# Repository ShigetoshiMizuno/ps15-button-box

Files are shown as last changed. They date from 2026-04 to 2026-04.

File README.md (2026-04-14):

# PS-15 Button Box

A 3D-printable single-button enclosure for the Seimitsu PS-15 arcade button.

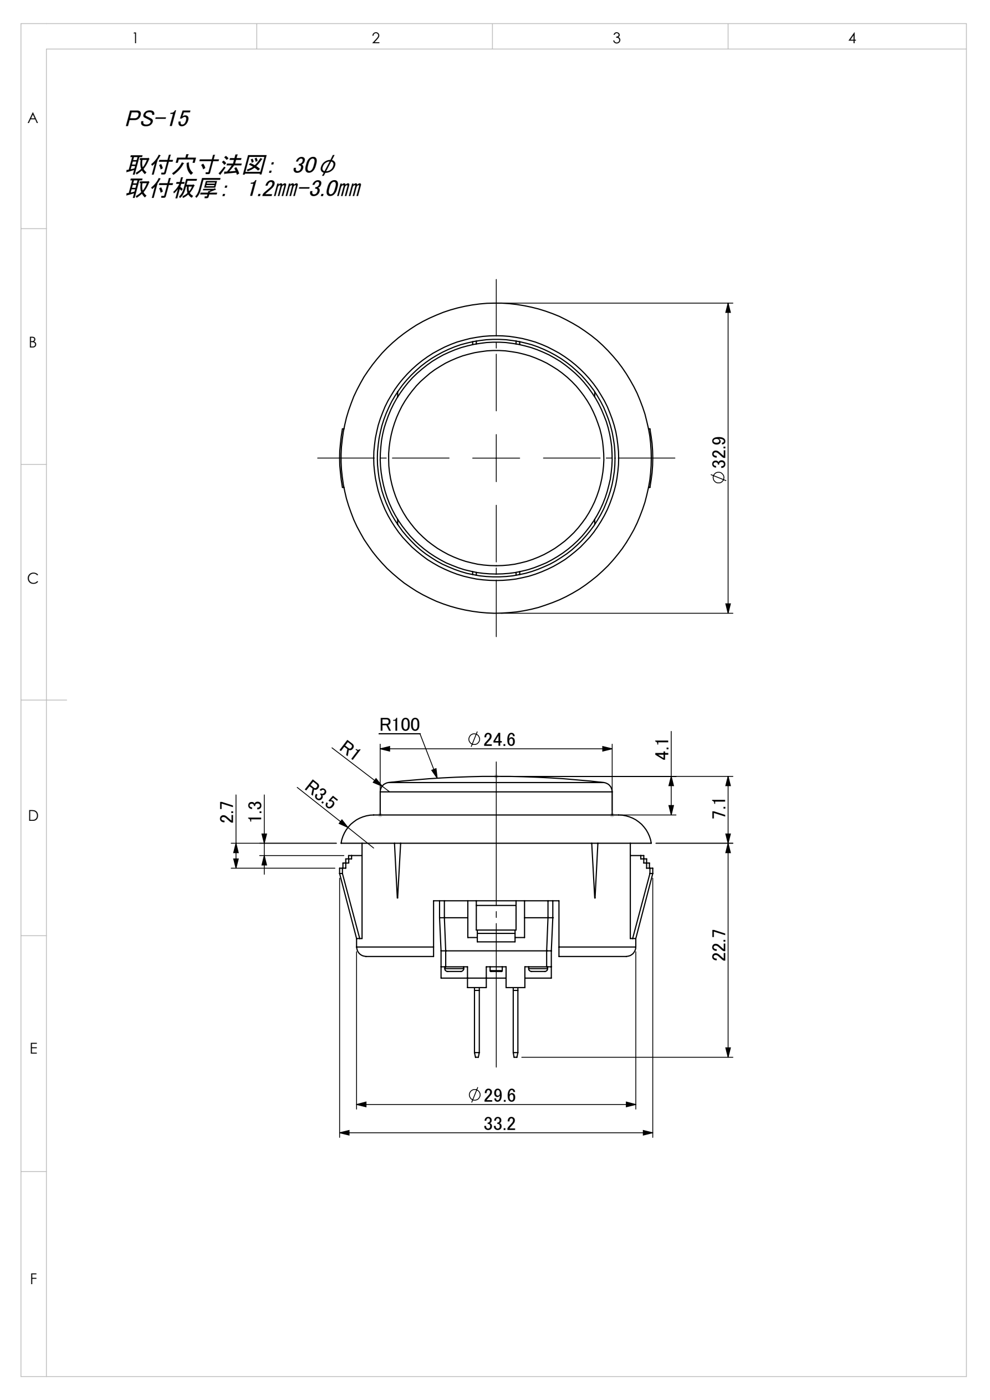
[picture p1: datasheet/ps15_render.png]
PS-15 Box Render


## Features

- Designed for **Seimitsu PS-15** (φ30mm mount hole, 1.2–3.0mm panel thickness)
- **Perfect cube**: 47 × 47 × 47mm assembled (body 44mm + lid 3mm)
- **FDM-optimized**: +0.2mm hole compensation, no supports required for either part
- **Two-point diagonal fastening**: M3×50 button-head bolt + M3 heat-press insert nut (8mm)
- **Dual mounting**: screw to wooden panel (φ4 wood screw) or use standalone
- **Wire slot**: U-slot 12mm × 10mm on right side wall
- **Engravings**: "NongSoft LLC / 2026" inside box bottom + lid back

## Files

| File | Description |
|---|---|
| `ps15_box.scad` | OpenSCAD source (all parameters adjustable) |
| `ps15_box_body.stl` | Body STL for 3D printing |
| `ps15_lid.stl` | Lid STL for 3D printing |
| `ps15_box_body.step` | Body STEP (for CAD import) |
| `ps15_lid.step` | Lid STEP (for CAD import) |
| `ps15_box_spec.md` | Full specification sheet |
| `stl_to_step.py` | FreeCAD 1.1 STL→STEP conversion script |

## Print Settings

| Parameter | Value |
|---|---|
| Material | **PETG** (PLA not recommended — low heat deflection for heat inserts) |
| Layer height | 0.2mm |
| Walls | 6 perimeters |
| Infill | 30–40% Gyroid |
| Body orientation | Open side up, no supports |
| Lid orientation | Flat side (inner face) down, no supports |

## Hardware

| Item | Spec | Qty |
|---|---|-----|
| M3 button-head bolt | M3 × 50mm | 2 |
| Heat-press insert nut | M3, OD φ4.6mm, L 8mm, brass | 2 |
| Button | Seimitsu PS-15 | 1 |

**Insert nut sources:**
- MISUMI: `BNTS3-8` (M3, brass, L=8mm)
- Amazon.co.jp: uxcell / SUNGQ 50-pack

## OpenSCAD Usage

### Customizer

- **断面表示 (Section view)**: toggle `show_section`, choose axis and position
- **出力 (Export)**: set `render_part` — 0=view, 1=body, 2=lid

### Re-export STL

```bat
set SCAD="C:\Program Files\OpenSCAD\openscad.exe"
%SCAD% -D "render_part=1" -o ps15_box_body.stl ps15_box.scad
%SCAD% -D "render_part=2" -o ps15_lid.stl      ps15_box.scad
```

### Re-export STEP (requires FreeCAD 1.1)

```bat
freecadcmd.exe stl_to_step.py
```

## License

[MIT License](LICENSE)

---

*Designed by NongSoft LLC — 2026*

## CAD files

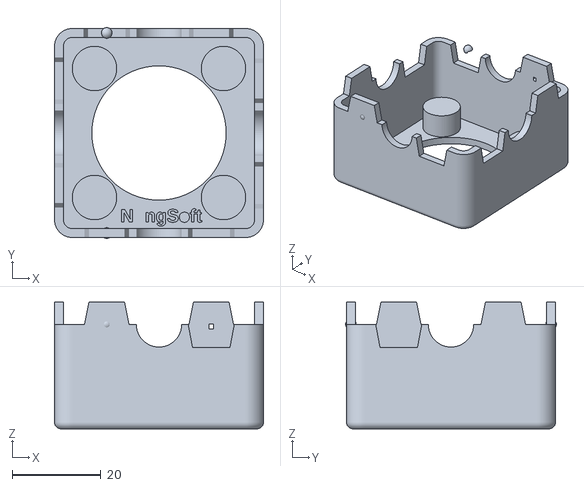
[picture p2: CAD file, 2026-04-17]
ps15_box_half.stl
47.0 x 47.4 x 28.5

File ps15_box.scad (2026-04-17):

// ============================================================
//  PS-15 スイッチボックス（1ボタン）v14 — 上下同一ハーフ設計
//  対象: Seimitsu PS-15
//  単位: mm
// ============================================================
//
//  【設計方針】
//    同一形状のハーフを2個印刷し、組み合わせてボックスを構成。
//    同じ印刷設定・同じ寸法誤差 → サイズ合わせ問題を根本解消。
//
//  【組立方法】
//    下ハーフ: 天面を上（正立）に置く
//    上ハーフ: ひっくり返して（天面を下向き）下ハーフに重ねる
//              → ボタン穴が最上面に来る
//    固定   : 4コーナー M3ボルト（長さは echo 参照）
//
//  【固定方式（4コーナー）】
//    インサートナット（M3）を下ハーフ底面外側から熱圧入
//    上ハーフ（反転）天面のカウンターボアからボルトを通す
//
//  【底面フィレット】接地面（Z=0側）の水平エッジ4本を R1.5mm でフィレット。
//                    反転した上ハーフの天面（組立時の上面）も同時に丸まる。
//                    合わせ面は直角を維持（ハーフ同士がぴったり接する）。
//
//  【配線】全4壁（前後左右）合わせ面に半円切り欠き（2ハーフ合体で円φ10mm）
//          連接時（daisy-chain）に各方向へケーブルが通せる
//
//  【位置合わせ（ラップジョイント・段継ぎ方式）】
//    E/W（東西）壁の合わせ面（Z=HALF_H）に段差δ=1.5mm の舌（凸）と溝（凹）を設ける。
//    下ハーフ E 壁に舌、W 壁に溝。反転した上ハーフは E/W が入れ替わり凸↔凹が噛み合う。
//    南(+Y) → 北(-Y) スライドで嵌合・自己ストップ。
//    変換: (x,y,z) → (OUTER_W-x, y, 2*HALF_H-z)
//
// ============================================================

/* ─── PS-15 仕様 ─── */
BTN_HOLE_D  = 30;    // 取付穴径 φ30mm
BTN_DEPTH   = 22.7;  // パネル下本体深さ（端子含む）

/* ─── ボックス基本寸法 ─── */
WALL        = 2.0;   // 側壁厚
BOT_T       = 2.0;   // 底面板厚（ボタン穴・cbore・インサート穴が集中する面）
HALF_H      = 23.5;  // 各ハーフ高さ
// 各ハーフはオープンカップ設計: Z=0〜BOT_T が底板、Z=BOT_T〜HALF_H が開口内部
INNER_H_HALF = HALF_H - BOT_T;           // 各ハーフ内高 = 21.5mm（開口カップ）
INNER_W     = 43;    // 内寸 X
INNER_D     = 43;    // 内寸 Y
CORNER_R      = 4.0;   // 外形コーナー半径
BOTTOM_FILLET = 1.5;   // 底面4辺のフィレット半径（合わせ面はシャープ保持）
INNER_CORNER_R = CORNER_R - WALL;        // 内壁コーナー半径 = 2mm

/* ─── 固定穴（4コーナー）─── */
MOUNT_INSET  = 9.0;  // コーナーからの内側オフセット（最小 9mm）
MOUNT_HOLE_D = 4.5;  // クリアランス穴径（M3 ボルト用）
MOUNT_CBORE_D= 9.0;  // カウンターボア径（M3 ボタンヘッドボルト頭）
CBORE_H      = 1.0;  // カウンターボア深さ（残し厚 = BOT_T - CBORE_H = 1.0mm）

/* ─── M3 インサートナット（熱圧入・底面外側から挿入）─── */
INSERT_OD   = 4.6;   // インサートナット外径
INSERT_L    = 8.0;   // インサートナット長さ
PILOT_D     = INSERT_OD + 0.1;           // 下穴径 = 4.7mm
PILOT_DEPTH = INSERT_L + 0.5;            // 下穴深さ = 8.5mm

/* ─── 内側ボス（底面板内側に突出）─── */
// ボス高さ = 下穴深さ - 底板厚 → ボス上面が下穴の上端に一致
BOSS_H      = PILOT_DEPTH - BOT_T;       // 6.5mm
BOSS_OD     = 10.0;  // ボス外径（≥ 2×INSERT_OD = 9.2mm）

/* ─── 位置合わせ凸凹（E/W壁・合わせ面 ラップジョイント方式）─── */
// 段継ぎ: E壁内側 1mm に舌（凸）、W壁内側 1mm に溝（凹）を配置。
// 下ハーフ反転で凸↔凹が入れ替わり噛み合う（同一ハーフ設計）。
STEP_DELTA   = 1.5;    // 段差高さ（mm）
STEP_Y_START = 29;     // 舌/溝 Y 開始位置（mm）
STEP_Y_END   = 43;     // 舌/溝 Y 終了位置（mm）
STEP_CLEAR   = 0.35;   // FDM 片側クリア（バンプ頂点+0.3mm分+余裕0.05mm確保）

// ---- ディテント (E1: 球バンプ) ----
DETENT_BUMP_R  = 0.30;   // バンプ半径（舌上面に凸）
DETENT_DIVOT_R = 0.45;   // ディンプル半径（溝天井に凹、CLEAR込み）
DETENT_Y       = (STEP_Y_START + STEP_Y_END) / 2;  // = 36（ストローク中央）

/* ─── 配線穴（合わせ面・半円切り欠き／合体で円形）─── */
// 全4壁に配置（連接時 daisy-chain 対応）
WIRE_D = 10.0;   // 合体時の円径（各ハーフは半円切り欠き）

/* ─── 算出値 ─── */
OUTER_W = INNER_W + 2 * WALL;   // 47.0mm
OUTER_D = INNER_D + 2 * WALL;   // 47.0mm

$fn = 64;

/* [断面表示] */
show_section = true;   // 断面表示を有効にする
cut_axis = 2;          // [0:X軸, 1:Y軸, 2:Z軸]
// デフォルト = MAX → スライダー最大位置でモデル全体が表示される
// X: ハーフ1(0-47) + gap(15) + ハーフ2(62-109) → MAX=110 で全表示
cut_x = 110;           // [0:1:110]
// Y: 外寸 47mm → MAX=50 で全表示
cut_y = 50;            // [0:1:50]
// Z: 0〜HALF_H=23.5mm → MAX=25 で全表示
cut_z = 25;            // [0:1:25]

/* [出力] */
// 0: ビュー  1: ハーフ単体（STL出力用）
render_part = 0;       // [0:ビュー, 1:ハーフ単体]
// FDM 収縮補正: 穴径を指定値だけ拡大（ボス等の外形には不適用）
hole_comp = 0.2;       // [0:0.05:0.5]

// 4コーナー: 前左・前右・後左・後右
mount_pts = [
    [MOUNT_INSET,             MOUNT_INSET            ],  // 前左
    [OUTER_W - MOUNT_INSET,   MOUNT_INSET            ],  // 前右
    [MOUNT_INSET,             OUTER_D - MOUNT_INSET  ],  // 後左
    [OUTER_W - MOUNT_INSET,   OUTER_D - MOUNT_INSET  ]   // 後右
];

// ============================================================
//  モジュール: 角Rつき矩形柱
// ============================================================
module rounded_box(w, d, h, r) {
    hull() {
        translate([    r,     r, 0]) cylinder(r = r, h = h);
        translate([w - r,     r, 0]) cylinder(r = r, h = h);
        translate([    r, d - r, 0]) cylinder(r = r, h = h);
        translate([w - r, d - r, 0]) cylinder(r = r, h = h);
    }
}

// ============================================================
//  モジュール: 外殻（底面4辺フィレット・合わせ面はシャープ）
//    minkowski で球をスイープしてフィレット生成、上端は cube でクリップ
// ============================================================
module outer_shell() {
    r = BOTTOM_FILLET;
    intersection() {
        minkowski() {
            translate([r, r, r])
                rounded_box(OUTER_W - 2*r, OUTER_D - 2*r, HALF_H - r, CORNER_R - r);
            sphere(r = r);
        }
        // 上端クリップ（合わせ面 Z=HALF_H 以上を落として直角に保つ）
        cube([OUTER_W, OUTER_D, HALF_H]);
    }
}

// ============================================================
//  モジュール: 配線穴（4壁・合わせ面半円切り欠き）
//    合わせ面 Z=HALF_H に中心を持つ円柱を各壁中央に配置 → 壁の上端を半円に切り欠く
//    2ハーフ合体で円φWIRE_D になる（daisy-chain 連接時は各方向にケーブル通し可）
// ============================================================
module wire_half_hole() {
    hole_d = WIRE_D + hole_comp;
    // 前壁（Y=0）: 軸Y方向
    translate([OUTER_W / 2, -0.1, HALF_H])
        rotate([-90, 0, 0])
            cylinder(d = hole_d, h = WALL + 0.2);
    // 後壁（Y=OUTER_D）: 軸Y方向
    translate([OUTER_W / 2, OUTER_D - WALL - 0.1, HALF_H])
        rotate([-90, 0, 0])
            cylinder(d = hole_d, h = WALL + 0.2);
    // 左壁（X=0）: 軸X方向
    translate([-0.1, OUTER_D / 2, HALF_H])
        rotate([0, 90, 0])
            cylinder(d = hole_d, h = WALL + 0.2);
    // 右壁（X=OUTER_W）: 軸X方向
    translate([OUTER_W - WALL - 0.1, OUTER_D / 2, HALF_H])
        rotate([0, 90, 0])
            cylinder(d = hole_d, h = WALL + 0.2);
}

// ============================================================
//  モジュール: ラップジョイント 舌（凸） — union() 内で呼ぶ
//    E 壁（X = OUTER_W - WALL）内側 1mm に配置。
//    合わせ面 Z=HALF_H を中心に ±STEP_DELTA/2 突出。
//    反転した上ハーフでは W 壁に現れ、下ハーフの W 壁溝に噛み合う。
// ============================================================
module step_tongue() {
    translate([OUTER_W - WALL, STEP_Y_START, HALF_H - STEP_DELTA / 2])
        cube([1.0, STEP_Y_END - STEP_Y_START, STEP_DELTA]);
}

// ============================================================
//  モジュール: ラップジョイント 溝（凹） — difference() 内で呼ぶ
//    W 壁（X = 0〜WALL）内側 1mm に配置。
//    STEP_CLEAR を片側に付与してFDM干渉を回避。
//    X のオーバーラン -0.1mm は CGAL 演算誤差回避のため必須。
// ============================================================
module step_groove() {
    translate([-0.1, STEP_Y_START - STEP_CLEAR, HALF_H - STEP_DELTA / 2 - STEP_CLEAR])
        cube([
            1.0 + STEP_CLEAR + 0.1,
            (STEP_Y_END - STEP_Y_START) + 2 * STEP_CLEAR,
            STEP_DELTA + 2 * STEP_CLEAR
        ]);
}

// ============================================================
//  モジュール: ディテント バンプ（凸） — union() 内で呼ぶ
//    下ハーフ E 壁・舌の上面中央に半球バンプ
//    バンプ中心: (舌中央X, DETENT_Y, 舌上面Z=HALF_H+STEP_DELTA/2)
// ============================================================
module detent_bump() {
    translate([OUTER_W - WALL/2, DETENT_Y, HALF_H + STEP_DELTA/2])
        sphere(r = DETENT_BUMP_R, $fn = 24);
}

// ============================================================
//  モジュール: ディテント ディンプル（凹） — difference() 内で呼ぶ
//    下ハーフ W 壁・溝の底面中央に半球ディンプル
//    ディンプル中心: (溝中央X, DETENT_Y, 溝底面Z=HALF_H-STEP_DELTA/2-STEP_CLEAR)
// ============================================================
module detent_divot() {
    translate([WALL/2, DETENT_Y, HALF_H - STEP_DELTA/2 - STEP_CLEAR])
        sphere(r = DETENT_DIVOT_R, $fn = 24);
}

// ============================================================
//  モジュール: ハーフ本体（上下共通・1種類のみ）
//    原点 = 底面外側・前左コーナー
//    天面（Z = HALF_H 側）: ボタン穴 + カウンターボア（反転時に上に来る）
//    底面（Z = 0 側）     : インサート下穴 + ボス（正立時に台座になる）
//    開口端（Z = HALF_H 側）: 位置合わせ凸凹（E/W壁ラップジョイント方式）
// ============================================================
module half_body() {
    difference() {
        union() {
            // ① 外殻（天面 + 底面 + 側壁）
            difference() {
                outer_shell();

                // 内部空洞はそのまま（内壁はシャープでOK）
                translate([WALL, WALL, BOT_T])
                    rounded_box(INNER_W, INNER_D, HALF_H, INNER_CORNER_R);

                // 配線穴（4壁合わせ面半円切り欠き・合体で円形・daisy-chain対応）
                wire_half_hole();
            }

            // ② 内側ボス（底面板内側・4コーナー）
            for (p = mount_pts) {
                translate([p[0], p[1], BOT_T])
                    cylinder(d = BOSS_OD, h = BOSS_H);
            }

            // ③ ラップジョイント 舌（E壁内側・合わせ面±STEP_DELTA/2）
            step_tongue();
            detent_bump();
        }

        // ④ インサート下穴（底面外側から・底板 + ボスを貫通）
        //    エントリ 1mm: 45°面取り
        //    残り: ストレート φ4.7mm
        for (p = mount_pts) {
            translate([p[0], p[1], -0.1]) {
                // 45°エントリ面取り（底面外側から 1mm）
                cylinder(d1 = PILOT_D + hole_comp + 2, d2 = PILOT_D + hole_comp, h = 1.1);
                // ストレート部
                cylinder(d = PILOT_D + hole_comp, h = PILOT_DEPTH + 0.1);
            }
        }
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

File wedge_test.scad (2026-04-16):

// ============================================================
//  wedge_test.scad — 楔凸/凹 3案 目視比較テスト
//
//  目的: 「凹側の壁はいらない」解釈の目視判断
//  本番ファイル ps15_box.scad は変更しない
//
//  案A: socket 位置の壁を縦スロットで完全切り欠く
//  案B: socket を直方体切り欠き（テーパー無し）
//  案C: 凹を廃止し楔凸のみ（両位置に凸）
// ============================================================

/* ─── 共通パラメータ（本番と同値）─── */
WALL           = 2.5;
BOT_T          = 3.0;
HALF_H         = 23.5;
SEG_LEN        = 30.0;
WEDGE_TAN_BASE = 5.0;
WEDGE_TAN_TIP  = 4.0;
WEDGE_NORM     = WALL;
WEDGE_H        = 5.0;
SOCK_CLEAR     = 0.2;
SOCK_H         = 5.25;
SOCK_TAN_OPEN  = 5.4;
SOCK_TAN_BOT   = 4.4;
$fn = 48;

/* ─── 基本セグメント: 底板＋壁 ─── */
module wall_seg() {
    // 底板
    cube([SEG_LEN, WALL, BOT_T]);
    // 壁（底板の上）
    translate([0, 0, BOT_T])
        cube([SEG_LEN, WALL, HALF_H - BOT_T]);
}

/* ─── 楔凸（台形押出し、合わせ面から +Z 方向に突出）─── */
module wedge_bump(pos_x) {
    translate([pos_x, WALL/2, HALF_H])
        linear_extrude(height=WEDGE_H, scale=[WEDGE_TAN_TIP/WEDGE_TAN_BASE, 1])
            square([WEDGE_TAN_BASE, WEDGE_NORM], center=true);
}

/* ─── 案A: socket 位置の壁を縦スロットで完全切り欠く ─── */
module case_A() {
    difference() {
        union() {
            wall_seg();
            wedge_bump(SEG_LEN * 1/3);
        }
        // 縦スロット: 底板上面(Z=BOT_T)から合わせ面(Z=HALF_H)まで全高
        // 接線方向テーパー（下 SOCK_TAN_BOT → 上 SOCK_TAN_OPEN）
        translate([SEG_LEN * 2/3, WALL/2, BOT_T])
            linear_extrude(height=HALF_H - BOT_T + 0.1,
                           scale=[SOCK_TAN_OPEN/SOCK_TAN_BOT, 1])
                square([SOCK_TAN_BOT, WEDGE_NORM + 0.2], center=true);
    }
}

/* ─── 案B: socket を直方体切り欠き（テーパー無し）─── */
module case_B() {
    difference() {
        union() {
            wall_seg();
            wedge_bump(SEG_LEN * 1/3);
        }
        // 直方体切り欠き: 合わせ面から下に SOCK_H 分のみ
        translate([SEG_LEN * 2/3 - SOCK_TAN_OPEN/2, -0.1, HALF_H - SOCK_H])
            cube([SOCK_TAN_OPEN, WALL + 0.2, SOCK_H + 0.1]);
    }
}

/* ─── 案C: 凹廃止・楔凸のみ（接線 1/3 と 2/3 の両方に凸）─── */
module case_C() {
    wall_seg();
    wedge_bump(SEG_LEN * 1/3);
    wedge_bump(SEG_LEN * 2/3);
}

/* ─── ラベル ─── */
module label(txt) {
    translate([SEG_LEN/2, WALL/2, HALF_H + 10])
        linear_extrude(height=1)
            text(txt, size=6, halign="center", valign="center");
}

/* ─── 並置（X 方向に 40mm 間隔）─── */
// 案A: X = 0
translate([0, 0, 0]) {
    case_A();
    label("A");
}

// 案B: X = SEG_LEN + 40 = 70
translate([70, 0, 0]) {
    case_B();
    label("B");
}

// 案C: X = 2 * (SEG_LEN + 40) = 140
translate([140, 0, 0]) {
    case_C();
    label("C");
}

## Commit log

2026-04-14 Initial release: PS-15 single-button arcade box
    OpenSCAD design + STL/STEP for a 47×47×47mm enclosure
    for the Seimitsu PS-15 arcade button. FDM-optimized with
    heat-press M3 insert nuts and dual-mounting (standalone/panel).
    [ps15_box.scad, ps15_box_body.stl, ps15_lid.stl]
2026-04-14 Add PowerShell clone script
2026-04-16 Redesign as symmetric upper/lower half (issue #2)
    - Switch from body+lid to identical half x2 (FDM tolerance absorbed)
    - Wedge locating keys on N/S walls only, point-symmetric layout
    (tangential taper 10->8, normal 2.0, H5 / socket 10.4->8.4, clear 0.2)
    - Cable holes phi10 on all 4 walls (mating surface) for daisy-chain
    - Bottom fillet R1.5 on 4 edges (mating surface sharp via minkowski+clip)
    - Diagonal 2-point M3 insert mount (finger access for PS-15 swap)
    - WALL 2.0 / BOT_T 2.0 / M3x55 bolts recommended
    Related files:
    - prompt_template.md: reusable prompt for similar box designs
    - wedge_test.scad: A/B/C comparison for socket shape decision
    Closes #2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
    [ps15_box.scad, ps15_box_body.stl, ps15_box_half.stl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]
2026-04-16 Move "NongSoft LLC" engraving off boss; remove "2026"
    - Shift to (OUTER_W/2 + 5, 4.5) to clear front-left M3 boss phi10 @ (9,9)
    - Drop "2026" engraving per request
    [ps15_box.scad, ps15_box_half.stl]
2026-04-17 feat: 4コーナーボルト固定・4壁楔位置合わせに拡張 (v8)
    - mount_pts を対角2点から前左・前右・後左・後右の4コーナーへ変更
    - 楔（凸凹）を南北2壁から東西南北4壁に拡張（rotate([0,0,90])でY軸向き）
    - 点対称配置: 反転(x,y,z)→(W-x,y,2H-z)で全8点の凸凹が自然に噛み合う
    [ps15_box.scad]
2026-04-17 feat: スナップフィット爪を追加（4壁楔・4コーナーボルトベース v9）
    左右壁内面にカンチレバー爪（XY平面撓み）を追加。
    - 爪: WALL起点でX方向に延伸、先端に+X/-X方向フック返し（45°テーパー付き）
    - 受け穴: 同一ハーフに掘り込み、反転合わせで相手ハーフの爪を受ける
    - FDM積層方向(Z)に対してXY平面内撓み設計 → 層間剥離しにくい
    Closes #4
    [ps15_box.scad]
2026-04-17 fix: スナップ爪とソケットのY位置を分離（腕が消える不具合修正）
    arm(Y=D/4)とsocket(Y=3D/4)を同一壁上で分離し、
    differenceでarmが削除されていたバグを修正。
    反転対称性は楔と同じ点対称パターンで維持。
    [ps15_box.scad]
2026-04-17 refactor: スナップ腕→合わせ面ドームに全面置き換え (v10)
    カンチレバー腕（Z組立と噛み合わない設計）を廃止し、
    合わせ面に半球バンプ+受け穴（点対称2点）を追加。
    バンプR=1.2 > 受け穴R=1.1 の干渉量でクリック感を生成。
    反転合わせでバンプ(W/4)↔受け穴(3W/4)が対応。
    [ps15_box.scad]
2026-04-17 fix: スナップドームを壁断面中央に移動（空中浮遊バグ修正）
    バンプ・受け穴の Y 座標を空洞中央(OUTER_D/2)から
    前後壁断面中央(WALL/2, OUTER_D-WALL/2)に修正。
    前後壁4点配置に増強し、壁の固体材料に接続。
    [ps15_box.scad]
2026-04-17 feat: ツイストロック（バヨネット式）追加 (v11) closes #5
    前後壁外面にタブ（W6×H2.5×T1.5mm）を追加。
    45°回転挿入→45°ひねりでタブがスロットに嵌まりロック。
    点対称配置（前壁W/4・後壁3W/4）で同一STL×2が成立。
    [ps15_box.scad]
2026-04-17 feat: render_part=2 ツイスト確認モードを追加
    上ハーフを45°回転した差し込み直前状態を表示。
    タブとスロットの目視確認用。
    [ps15_box.scad]
2026-04-17 test: 楔形ロケーターを一時無効化（ツイストロック単体確認用）
    mating_bumps/mating_sockets をコメントアウト。
    render_part=2 でツイストロックの噛み合いを目視確認する。
    [ps15_box.scad]
2026-04-17 feat: ヘリカルランプ追加（前後壁・90°ひねりロック用傾斜面 v12）
    前後壁の合わせ面上端に楔形三角柱（RAMP_H=3mm）を追加。
    前壁: X=0（低）→ X=OUTER_W（高）
    後壁: X=0（高）→ X=OUTER_W（低）（点対称）
    render_part=2 で90°回転状態を目視確認可能。
    [ps15_box.scad]
2026-04-17 revert: ツイストロック／ヘリカルランプ廃止・スナップ座標修正
    - twist_tabs / twist_slots / helix_ramps モジュールと関連定数を削除
    - mating_bumps / mating_sockets を復活（楔形位置合わせ）
    - snap_bumps / snap_holes を前壁1ペアに整理
    - バンプ X=OUTER_W/3, 穴 X=OUTER_W*2/3（mating 配置と干渉しない位置）
    - 後壁バンプが mating_socket に削られ浮遊する問題を解消
    - render_part=2（ツイスト確認モード）を削除
    - STL / STEP を再生成
    上下連結は M3 ボルト4本を主固定とし、楔形＋スナップは軽保持用に限定。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
    [ps15_box.scad, ps15_box_half.stl]
2026-04-17 feat: 合わせ面をラップジョイント方式に置換 (v13) closes #6
    楔形(wedge)＋スナップフィット(snap)位置決め機構を撤去し、
    東西(E/W)壁の段差(δ=1.5mm)ラップジョイントに置き換え。
    南(+Y)→北(-Y)スライド嵌合で、舌南端が相手ボディに
    衝突して自己ストップ。
    - 削除: WEDGE_/SOCK_/SNAP_ 系 定数12個、モジュール6個
    - 追加: STEP_DELTA=1.5, STEP_Y_START=29, STEP_Y_END=43,
    STEP_CLEAR=0.15, step_tongue(), step_groove()
    - Y=[29,43] 配置で配線穴(Y=23.5)・M3ボス(X=9/38)と干渉なし
    - 同一ハーフ反転 (x,y,z)→(OUTER_W-x, y, 2*HALF_H-z) により
    下ハーフ E凸/W凹 が上ハー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
    [ps15_box.scad]
2026-04-17 feat: 球ディテント追加で Z 持ち上げ保持を強化 (v14)
    ラップジョイント単体ではZ方向の抜け止めが効かないため、
    合わせ面に「カチッ」と嵌合する球ディテント(E1)を追加。
    上半をつまんで持ち上げた際に下半が簡単に落下しない程度の
    保持力を確保する。
    - 追加定数: DETENT_BUMP_R=0.30, DETENT_DIVOT_R=0.45,
    DETENT_Y=36 (ストローク中央)
    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
    [ps15_box.scad]
